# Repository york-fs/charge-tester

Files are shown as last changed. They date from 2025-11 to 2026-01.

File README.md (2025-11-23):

# BMS Charging Tester Board







A CAN-controlled linear charging board for testing BMS features without a full charger.

Preview Render

## Cloning

A recursive clone must be used to download the `kicad-library` repository:

    git clone --recursive https://github.com/york-fs/charge-tester.git

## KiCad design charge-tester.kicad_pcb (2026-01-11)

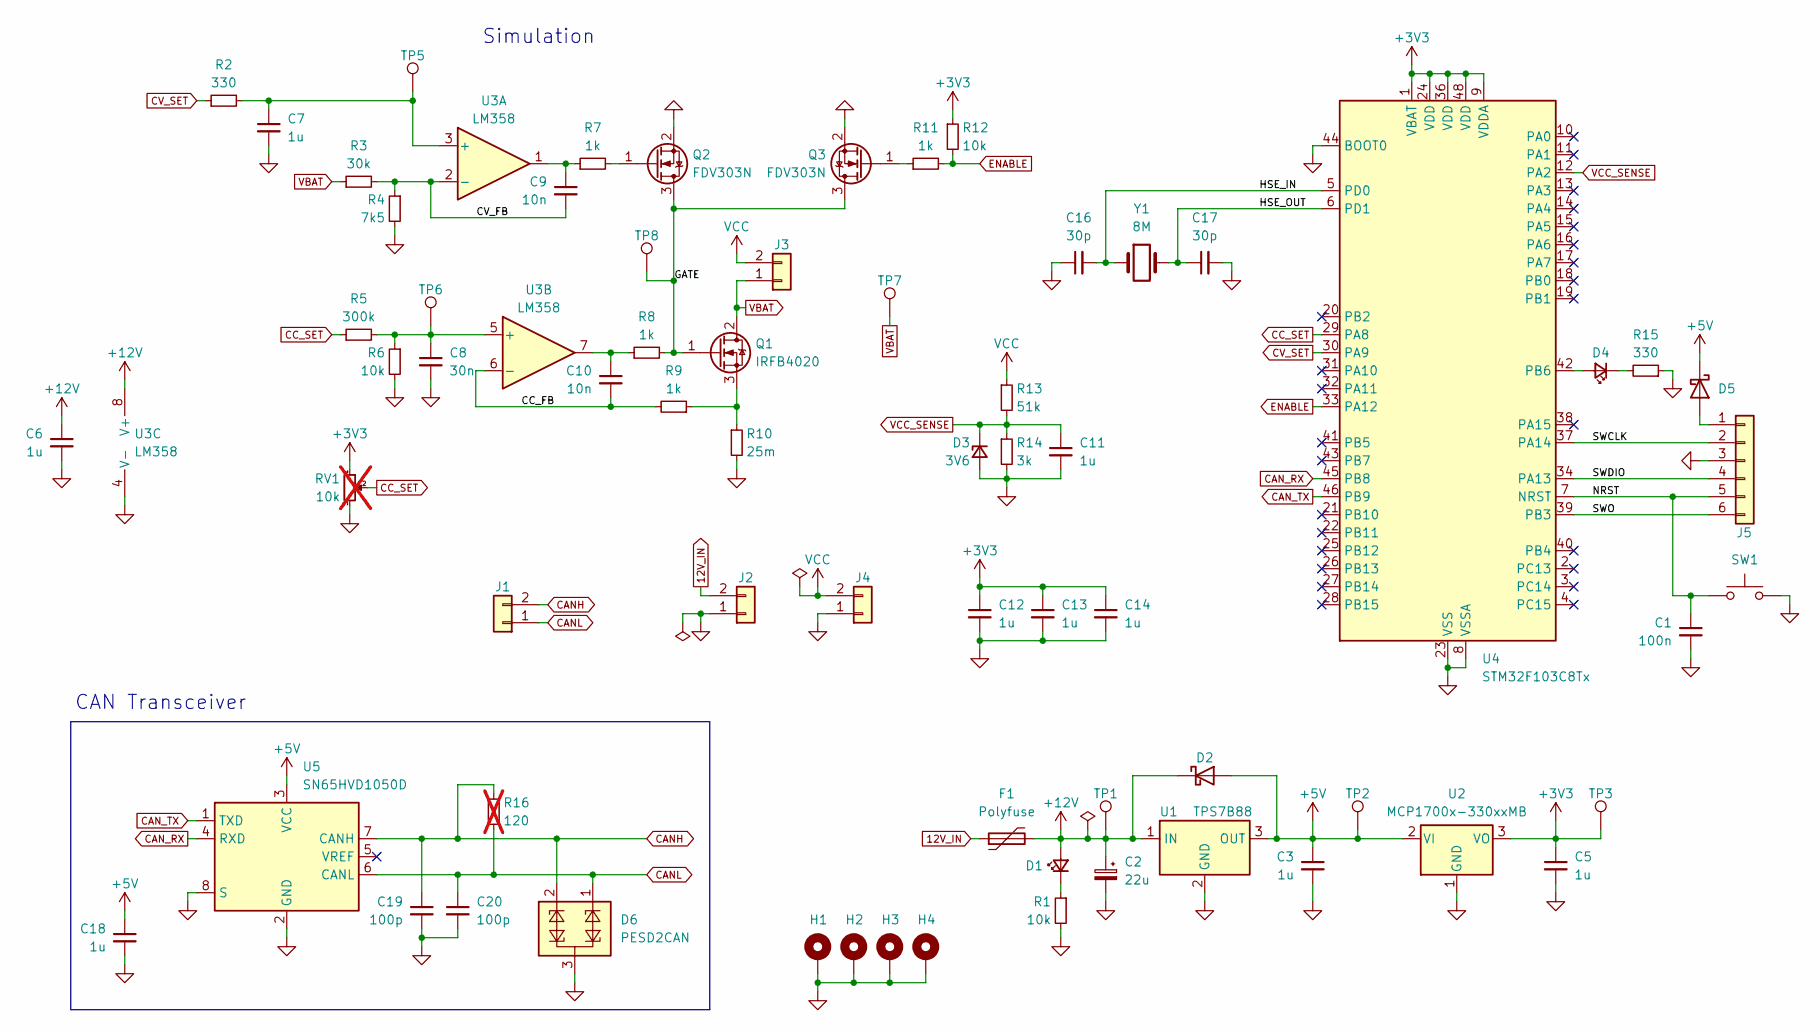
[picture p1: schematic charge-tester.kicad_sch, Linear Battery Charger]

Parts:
C1: 100n; C_0603_1608Metric; Mfr # CL10B104KB8NNNC
C2: 22u; CP_Elec_6.3x7.7; Mfr # EEEFK1J220XP
C3, C5, C6, C7, C11, C12, C13, C14, C18: 1u; C_0603_1608Metric; Mfr # CL10B105KB8NQNC
C8: 30n; C_0603_1608Metric
C9, C10: 10n; C_0603_1608Metric; Mfr # GRM1885C1H103JA01D
C16, C17: 30p; C_0603_1608Metric; Mfr # GQM1875C2E300GB12D
C19, C20: 100p; C_0603_1608Metric; Mfr # GCM1885C2A101JA16D
D1, D4: LED_Small; LED_0603_1608Metric; Mfr # NCD0603R1
D2, D5: D_Schottky; D_SOD-323; Mfr # NSR0530H
D3: 3V6; D_SOD-323; Mfr # BZX384C3V6
D6: PESD2CAN; SOT-23; Mfr # PESD2CAN,215
F1: Polyfuse; R_0805_2012Metric; Mfr # 0805L010/24YR
H1, H2, H3, H4: MountingHole_Pad; MountingHole_3.2mm_M3_Pad_Via
J1: Conn_01x02; MolexMicrofitPlus1x2; Mfr # 2157601012
J2: Conn_01x02; MolexMicrofitPlus1x2; Mfr # 2157601022
J3, J4: Conn_01x02; MolexMicrofitPlus1x2; Mfr # 2157601002
J5: Conn_01x06; IDC-Connector-2x3; Mfr # HX JN1.27-2x3P ZZ H4.9
Q1: IRFB4020; TO-220-3_Vertical
Q2, Q3: FDV303N; SOT-23; Mfr # FDV303N
R1, R6, R12: 10k; R_0603_1608Metric; Mfr # 0603WAF1002T5E
R2, R15: 330; R_0603_1608Metric; Mfr # 0603WAF3300T5E
R3: 30k; R_0603_1608Metric
R4: 7k5; R_0603_1608Metric
R5: 300k; R_0603_1608Metric
R7, R8, R9, R11: 1k; R_0603_1608Metric; Mfr # 0603WAF1001T5E
R10: 25m; R_1206_3216Metric; Mfr # HoJLR1206-1W-25mR-1%
R13: 51k; R_0603_1608Metric
R14: 3k; R_0603_1608Metric; Mfr # 0603WAF3001T5E
R16: 120; R_0603_1608Metric; not fitted
RV1: 10k; Potentiometer_Bourns_3296W_Vertical; not fitted
SW1: SW_Push; SW_Push_1P1T_NO_Vertical_Wuerth_434133025816; Mfr # SKRPACE010
TP1, TP2, TP3, TP5, TP6, TP7, TP8: TestPoint; TestPoint_Keystone_5000-5004_Miniature
U1: TPS7B88; TO-252-2; Mfr # TPS7B8850QKVURQ1
U2: MCP1700x-330xxMB; SOT-89-3; Mfr # MCP1700T-3302E/MB
U3: LM358; SOIC-8_3.9x4.9mm_P1.27mm; Mfr # LM358BAIDR
U4: STM32F103C8Tx; LQFP-48_7x7mm_P0.5mm; Mfr # STM32F103C8T6
U5: SN65HVD1050D; SOIC-8_3.9x4.9mm_P1.27mm; Mfr # SN65HVD1050DR
Y1: 8M; Crystal_SMD_5032-2Pin_5.0x3.2mm; Mfr # X50328MSB2GI

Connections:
12V_IN: F1.1, J2.2
+3V3: C5.1, C12.1, C13.1, C14.1, R12.1, RV1.1, TP3.1, U2.3 (VO), U4.1 (VBAT), U4.9 (VDDA), U4.24 (VDD), U4.36 (VDD), U4.48 (VDD)
+5V: C3.1, C18.1, D2.2 (A), D5.1 (K), TP2.1, U1.3 (OUT), U2.2 (VI), U5.3 (VCC)
+12V: C2.1, C6.1, D1.2 (A), D2.1 (K), F1.2, TP1.1, U1.1 (IN), U3.8 (V+)
/CC_FB: C10.2, R9.2, U3.6 (-)
/CV_FB: C9.2, R3.2, R4.1, U3.2 (-)
/GATE: Q1.1 (G), Q2.3 (D), Q3.3 (D), R8.2, TP8.1
/HSE_IN: C16.2, U4.5 (PD0), Y1.1
/HSE_OUT: C17.1, U4.6 (PD1), Y1.2
/NRST: C1.1, J5.5, SW1.1, U4.7 (NRST)
/SWCLK: J5.2, U4.37 (PA14)
/SWDIO: J5.4, U4.34 (PA13)
/SWO: J5.6, U4.39 (PB3)
CANH: C19.1, D6.2 (C2), J1.2, R16.1, U5.7 (CANH)
CANL: C20.1, D6.1 (C1), J1.1, R16.2, U5.6 (CANL)
CAN_RX: U4.45 (PB8), U5.4 (RXD)
CAN_TX: U4.46 (PB9), U5.1 (TXD)
CC_SET: R5.1, RV1.2, U4.29 (PA8)
CV_SET: R2.1, U4.30 (PA9)
ENABLE: R11.2, R12.2, U4.33 (PA12)
GND: C1.2, C2.2, C3.2, C5.2, C6.2, C7.2, C8.2, C11.2, C12.2, C13.2, C14.2, C16.1, C17.2, C18.2, C19.2, C20.2, D3.2 (A), D6.3 (CC), H1.1, H2.1, H3.1, H4.1, J2.1, J4.1, J5.3, Q2.2 (S), Q3.2 (S), R1.2, R4.2, R6.2, R10.2, R14.2, R15.1, RV1.3, SW1.2, U1.2 (GND), U2.1 (GND), U3.4 (V-), U4.8 (VSSA), U4.23 (VSS), U4.35 (VSS), U4.44 (BOOT0), U4.47 (VSS), U5.2 (GND), U5.8 (S)
unnamed: C9.1, R7.1, U3.1
unnamed: C10.1, R8.1, U3.7
unnamed: D1.1 (K), R1.1
unnamed: D4.2 (A), U4.42 (PB6)
unnamed: D4.1 (K), R15.2
unnamed: D5.2 (A), J5.1
unnamed: Q1.3 (S), R9.1, R10.1
unnamed: Q2.1 (G), R7.2
unnamed: Q3.1 (G), R11.1
unnamed: C7.1, R2.2, TP5.1, U3.3 (+)
unnamed: C8.1, R5.2, R6.1, TP6.1, U3.5 (+)
VBAT: J3.1, Q1.2 (D), R3.1, TP7.1
VCC: J3.2, J4.2, R13.1
VCC_SENSE: C11.1, D3.1 (K), R13.2, R14.1, U4.12 (PA2)

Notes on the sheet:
Simulation
CAN Transceiver

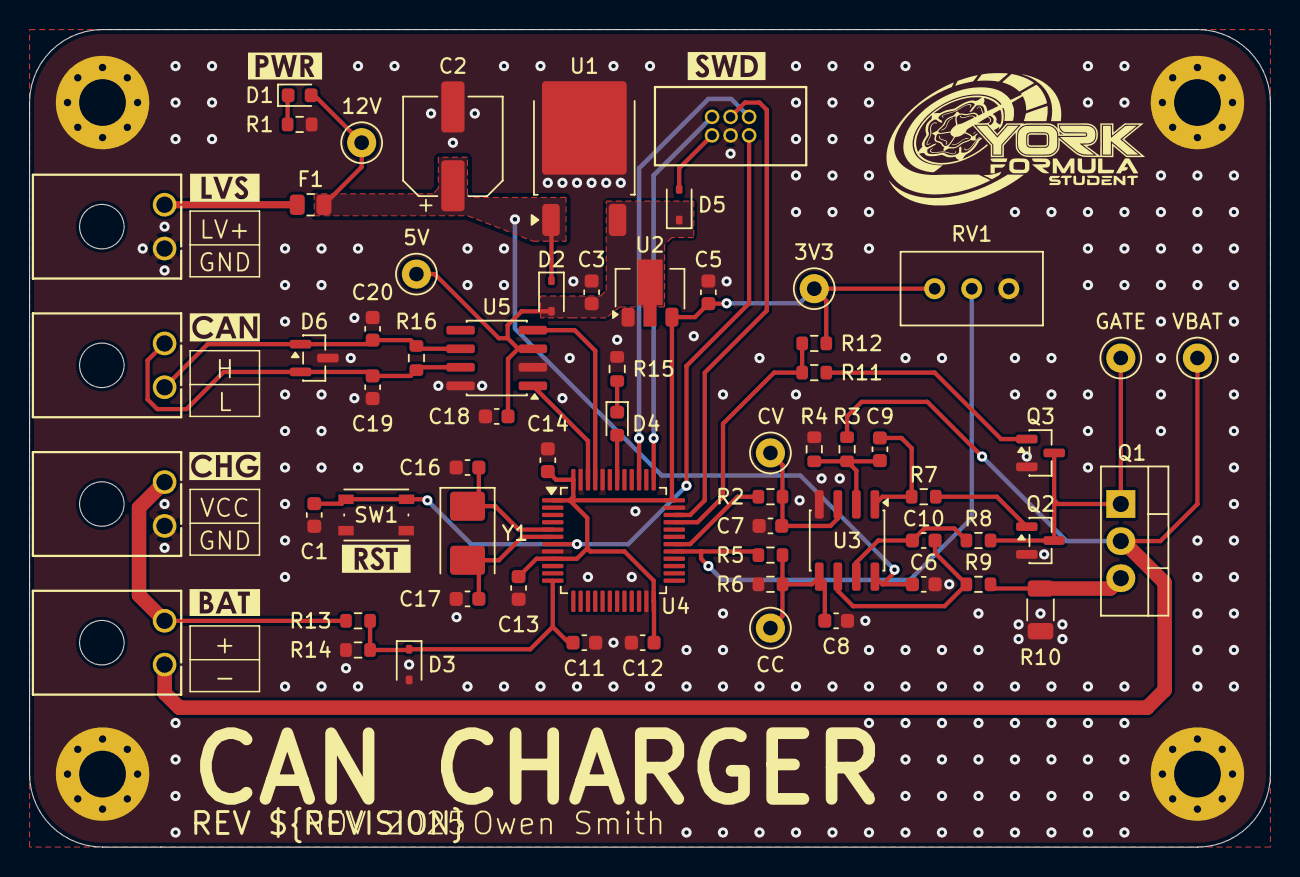
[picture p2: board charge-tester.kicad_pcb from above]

Board: 2 copper layers, 85.0 x 56.0 mm, 75 parts (0 on the bottom side), 35 nets.

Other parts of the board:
kibuzzard-691F9AB4: G***; kibuzzard-691F9AB4
kibuzzard-691FA72C: G***; kibuzzard-691FA72C
kibuzzard-6910B7D7: G***; kibuzzard-6910B7D7
kibuzzard-6910B743: G***; kibuzzard-6910B743
kibuzzard-6910BB6B: G***; kibuzzard-6910BB6B
kibuzzard-6910BB45: G***; kibuzzard-6910BB45
kibuzzard-6910BB76: G***; kibuzzard-6910BB76

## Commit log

2025-11-20 schematic: Assign footprints and fill out BOM
    [charge-tester.kicad_sch]
2025-11-20 schematic: Add some more test points and net labels
    [charge-tester.kicad_sch]
2025-11-21 *: Initial layout
    [charge-tester.kicad_pcb, charge-tester.kicad_sch]
2025-11-21 pcb: Upgrade to 1 mm traces for the main current path
    [charge-tester.kicad_pcb]
2025-11-21 pcb: Improve silkscreen
    [charge-tester.kicad_pcb]
2025-11-22 *: Fill in info boxes
    [charge-tester.kicad_pcb, charge-tester.kicad_sch]
2025-11-22 pcb: Run cleanup tracks
    [charge-tester.kicad_pcb]
2025-11-22 pcb: Set gerber output parameters
    [charge-tester.kicad_pcb]
2025-11-23 ci: Add kicad workflow
2025-12-06 schematic: Switch op-amp to LM358BA
    [charge-tester.kicad_pcb, charge-tester.kicad_sch]
2026-01-11 bom: Fix incorrect 3k resistor part number
    [charge-tester.kicad_pcb, charge-tester.kicad_sch]
